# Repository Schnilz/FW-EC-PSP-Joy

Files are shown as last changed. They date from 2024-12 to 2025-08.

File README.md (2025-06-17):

# PSP Joystick Framework Laptop Expansion Card

A joystick expansion card with 2 buttons and the low profile psp joystick.

<p float="left" style="display: flex; flex-wrap: wrap; align-items: center;">
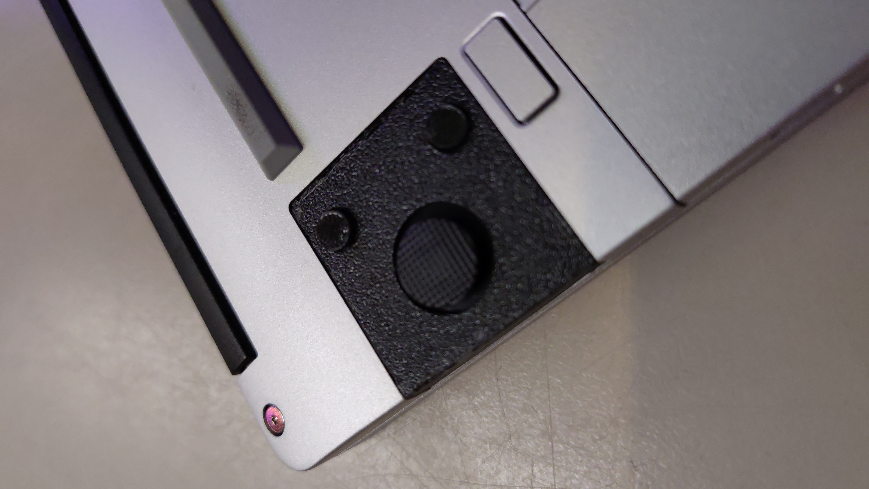
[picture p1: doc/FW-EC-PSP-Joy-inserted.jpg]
  &nbsp;
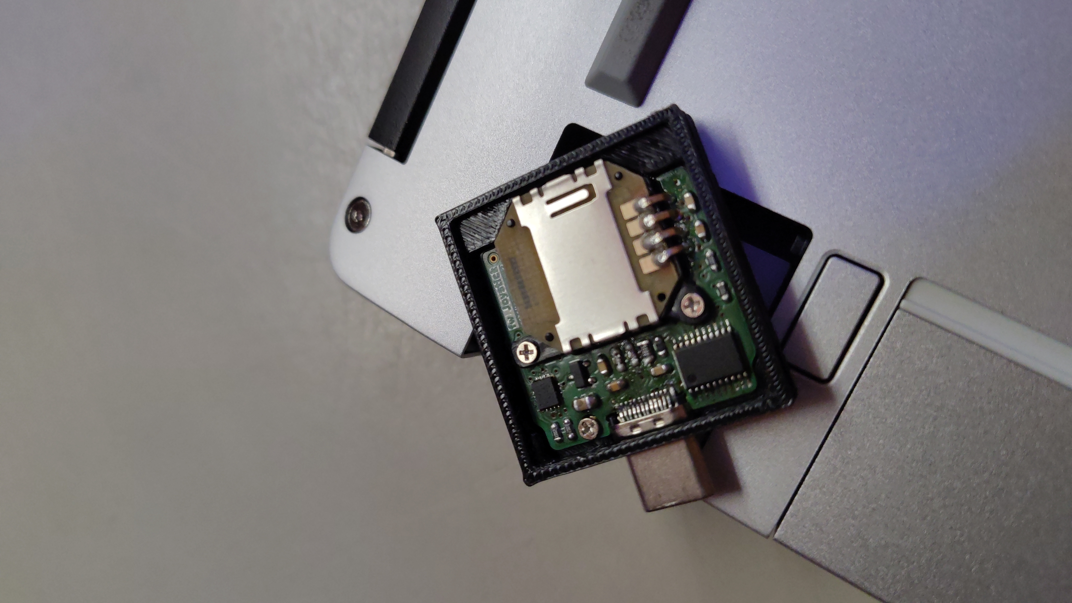
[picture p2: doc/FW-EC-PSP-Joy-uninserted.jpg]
  
</p>

This uses the 10cent risc-v ch32v003 with ch32fun and its software-USB stack rv003usb to power this HID device. 

## PCB

<p float="left" style="display: flex; flex-wrap: wrap; align-items: center;">
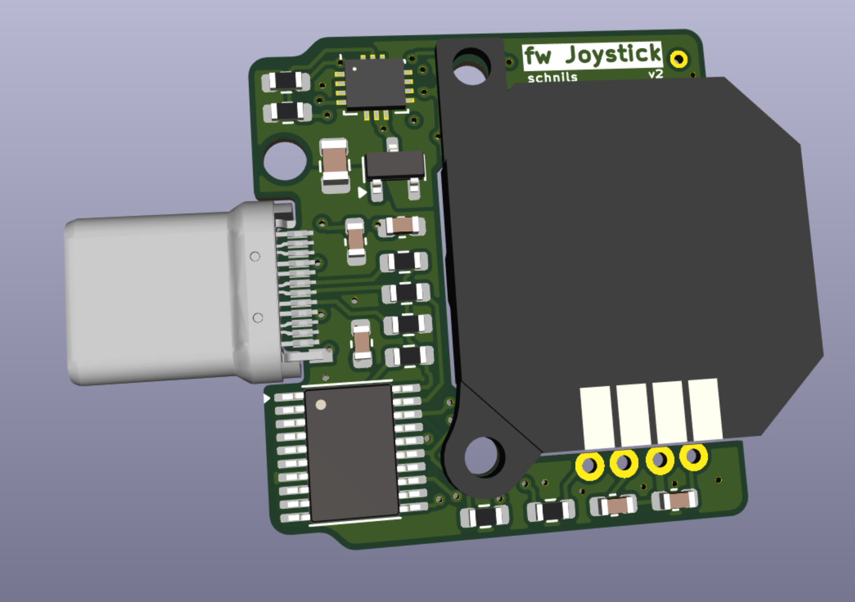
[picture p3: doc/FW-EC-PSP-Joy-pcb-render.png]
  &nbsp;
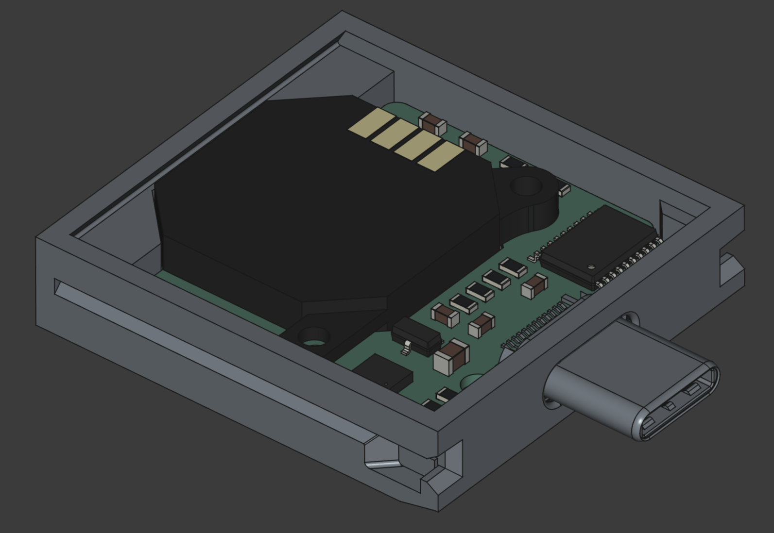
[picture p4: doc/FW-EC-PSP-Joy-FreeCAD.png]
  
</p>

## Thanks

Thanks to LeoDJ for open sourceing his FW-EC-DongleHiderPlus which this is based upon.

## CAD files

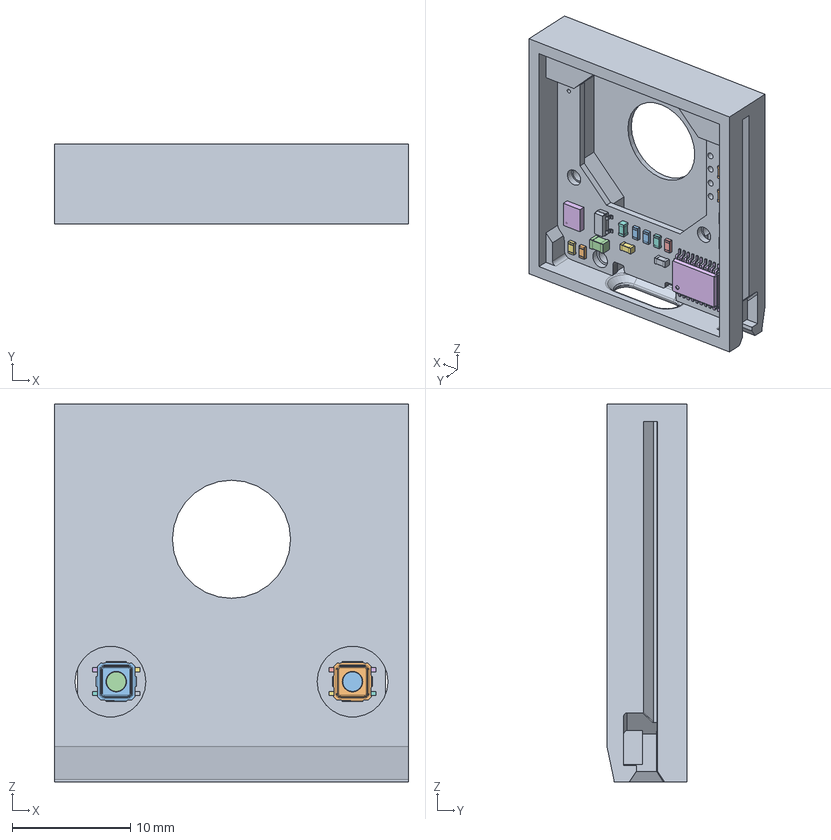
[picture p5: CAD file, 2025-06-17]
mechanical/fw-ce-case.FCStd
30.0 x 6.80 x 32.0 mm
R_0603_1608Metric016
R_0603_1608Metric018
C_0805_2012Metric002
R_0603_1608Metric020
TSSOP_20_44x65mm_P065mm001
R_0603_1608Metric022
R_0603_1608Metric024
C_0603_1608Metric010
C_0603_1608Metric012
R_0603_1608Metric026
R_0603_1608Metric028
R_0603_1608Metric030
Bosch_LGA_14_3x25mm_P05mm001
C_0603_1608Metric014
C_0603_1608Metric016
SOT_024
C_0603_1608Metric018
TS21-34-035-BK-260-SMT-TR v022
TS21-34-035-BK-260-SMT-TR v023
TS21-34-035-BK-260-SMT-TR v024
TS21-34-035-BK-260-SMT-TR v025
TS21-34-035-BK-260-SMT-TR v026
TS21-34-035-BK-260-SMT-TR v027
TS21-34-035-BK-260-SMT-TR v028
TS21-34-035-BK-260-SMT-TR v030
TS21-34-035-BK-260-SMT-TR v031
TS21-34-035-BK-260-SMT-TR v032
TS21-34-035-BK-260-SMT-TR v033
TS21-34-035-BK-260-SMT-TR v034
TS21-34-035-BK-260-SMT-TR v035
TS21-34-035-BK-260-SMT-TR v036
FWPSPJoystick_PCB001

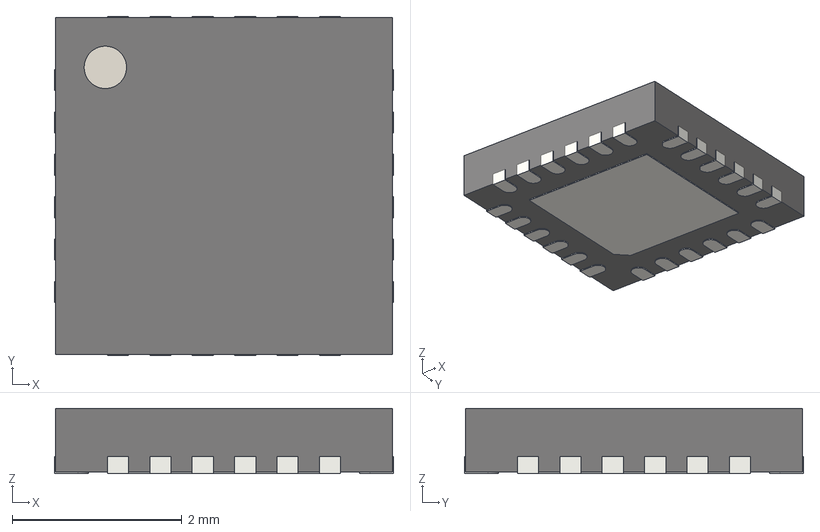
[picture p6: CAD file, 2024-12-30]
pcb/3dshapes/QFN-24-1EP_4x4mm_P0.5mm_EP2.6x2.6mm.step
4.00 x 4.00 x 0.77 mm

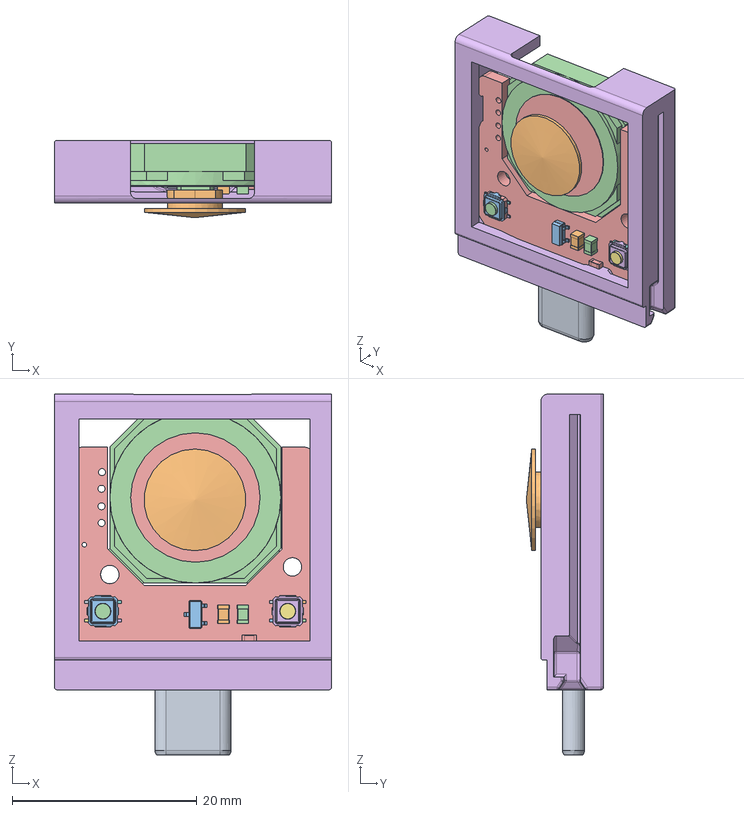
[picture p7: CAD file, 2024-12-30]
Mechanical/testfit.FCStd
30.0 x 8.37 x 39.1 mm
R_0603_1608Metric
C_0603_1608Metric
TSSOP_20_44x65mm_P065mm
PspJoystick v6
PspJoystick v007
PspJoystick v008
PspJoystick v009
PspJoystick v010
PspJoystick v011
PspJoystick v012
R_0603_1608Metric002
R_0603_1608Metric004
C_0603_1608Metric002
R_0603_1608Metric006
Bosch_LGA_14_3x25mm_P05mm
C_0603_1608Metric004
SOT_23_6
TS21-34-035-BK-260-SMT-TR v6
TS21-34-035-BK-260-SMT-TR v007
TS21-34-035-BK-260-SMT-TR v008
TS21-34-035-BK-260-SMT-TR v009
TS21-34-035-BK-260-SMT-TR v010
TS21-34-035-BK-260-SMT-TR v011
TS21-34-035-BK-260-SMT-TR v012
C_0805_2012Metric
SOT_23
C_0805_2012Metric002
C_0603_1608Metric006
TS21-34-035-BK-260-SMT-TR v014
TS21-34-035-BK-260-SMT-TR v015
TS21-34-035-BK-260-SMT-TR v016
TS21-34-035-BK-260-SMT-TR v017
TS21-34-035-BK-260-SMT-TR v018
TS21-34-035-BK-260-SMT-TR v019
TS21-34-035-BK-260-SMT-TR v020
FWPSPJoystick_PCB

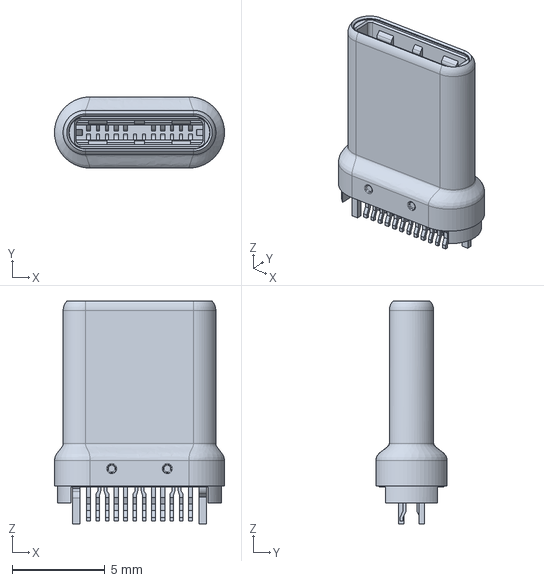
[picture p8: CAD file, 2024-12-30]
pcb/3dshapes/Molex_1054440011.stp
9.18 x 3.84 x 12.0 mm

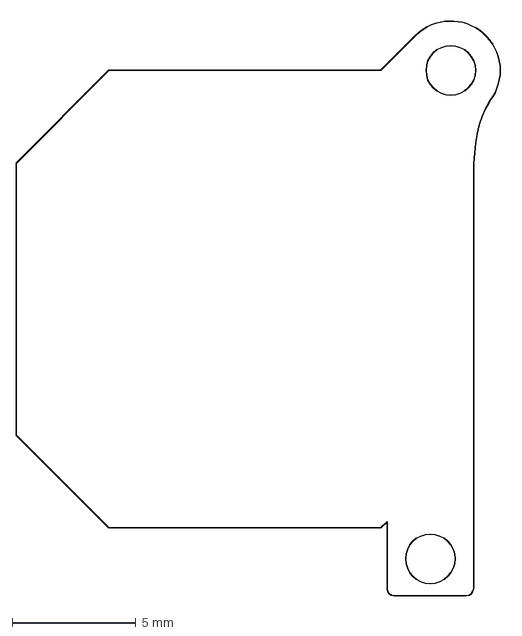
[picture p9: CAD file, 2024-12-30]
Mechanical/psp_joy_outline.dxf
19.8 x 23.4 mm

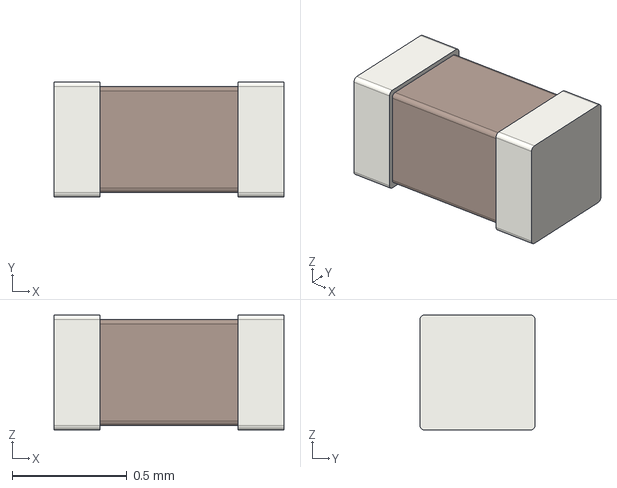
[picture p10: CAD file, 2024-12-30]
pcb/3dshapes/C_0402_1005Metric.step
1.00 x 0.5 x 0.5 mm

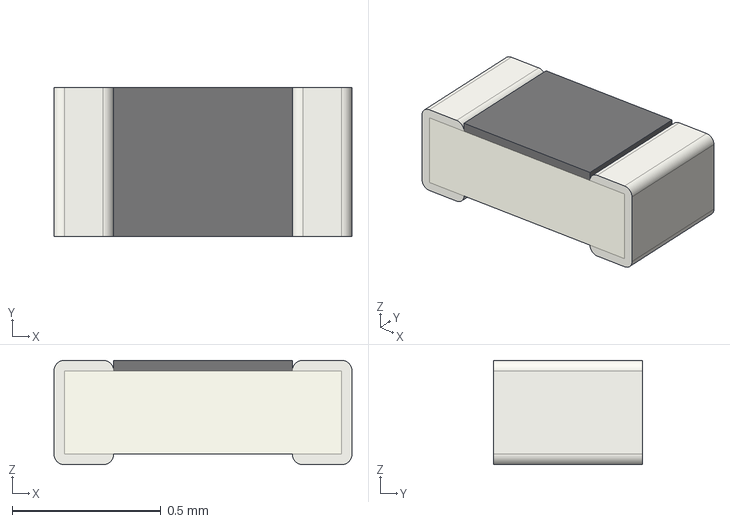
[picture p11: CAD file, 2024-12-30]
pcb/3dshapes/R_0402_1005Metric.step
1.00 x 0.5 x 0.35 mm

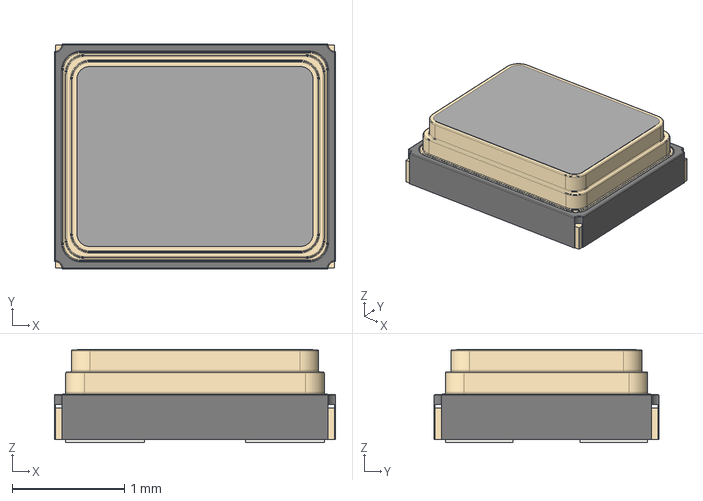
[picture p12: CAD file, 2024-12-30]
pcb/3dshapes/Crystal_SMD_2520-4Pin_2.5x2.0mm.step
2.50 x 2.00 x 0.83 mm

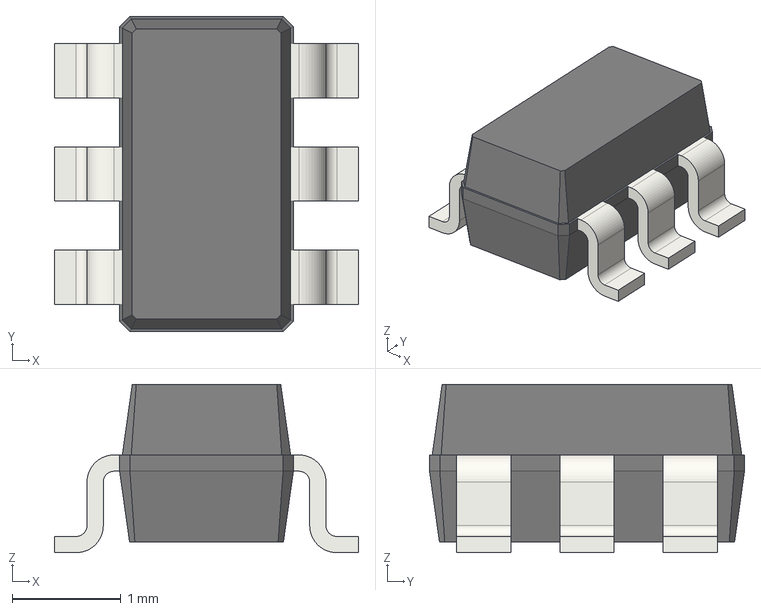
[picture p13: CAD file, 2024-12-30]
pcb/3dshapes/SOT-23-6.step
2.80 x 2.90 x 1.55 mm

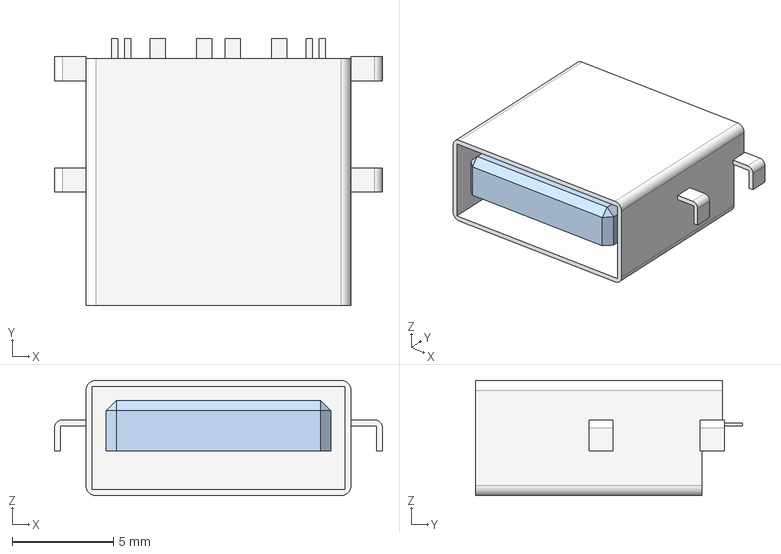
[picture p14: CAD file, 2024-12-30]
pcb/3dshapes/_HC-USB3.0-C345-P.step
16.2 x 13.2 x 5.70 mm

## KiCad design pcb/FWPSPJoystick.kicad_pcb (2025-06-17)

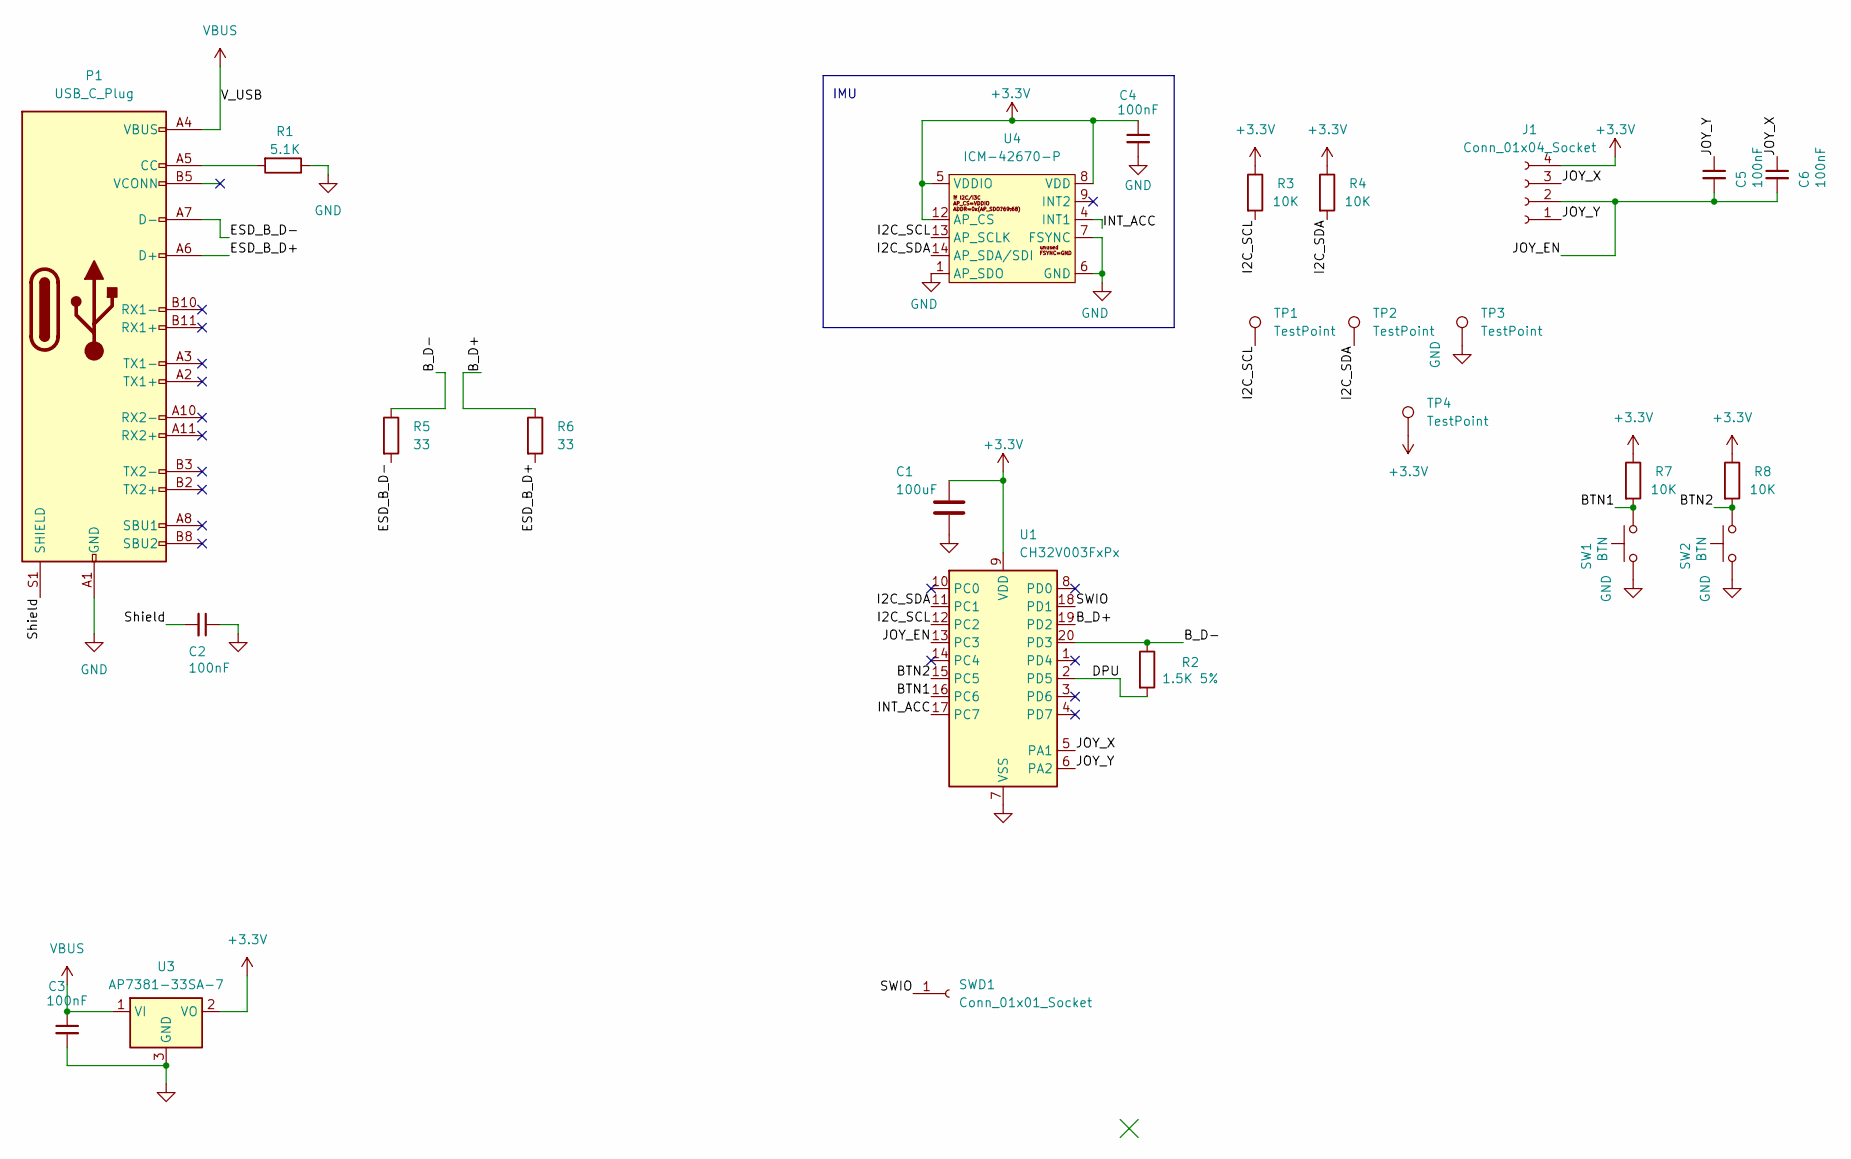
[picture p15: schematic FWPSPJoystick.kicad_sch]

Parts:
C1: 100uF; C_0805_2012Metric; LCSC C440198
C2, C5, C6: 100nF; C_0603_1608Metric; LCSC C14663
C3, C4: 100nF; C_0603_1608Metric
J1: Conn_01x04_Socket; pspjoystick_tht
P1: USB_C_Plug; USB_C_Plug_Molex_105444; LCSC C561769
R1: 5.1K; R_0603_1608Metric; LCSC C23186
R2: 1.5K 5%; R_0603_1608Metric; LCSC C23186
R3, R4, R7, R8: 10K; R_0603_1608Metric
R5, R6: 33; R_0603_1608Metric
SW1, SW2: BTN; TS21
SWD1: Conn_01x01_Socket; TestPoint_THTPad_D1.0mm_Drill0.5mm
TP1, TP2, TP3, TP4: TestPoint; TestPoint_Pad_D1.0mm
U1: CH32V003FxPx; TSSOP-20_4.4x6.5mm_P0.65mm
U3: AP7381-33SA-7; SOT-23
U4: ICM-42670-P; LGA-14_2.5x3x0.76mm

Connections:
+3.3V: C1.1, C4.1, J1.4, R3.1, R4.1, R7.1, R8.1, TP4.1, U1.9 (VDD), U3.2 (VO), U4.5 (VDDIO), U4.8 (VDD), U4.12 (AP_CS)
/BTN1: R7.2, SW1.2, U1.16 (PC6)
/BTN2: R8.2, SW2.2, U1.15 (PC5)
/B_D+: R6.1, U1.19 (PD2)
/B_D-: R2.1, R5.1, U1.20 (PD3)
/DPU: R2.2, U1.2 (PD5)
/ESD_B_D+: P1.A6 (D+), R6.2
/ESD_B_D-: P1.A7 (D-), R5.2
/I2C_SCL: R3.2, TP1.1, U1.12 (PC2), U4.13 (AP_SCLK)
/I2C_SDA: R4.2, TP2.1, U1.11 (PC1), U4.14 (AP_SDA/SDI)
/INT_ACC: U1.17 (PC7), U4.4 (INT1)
/JOY_EN: C5.2, C6.2, J1.2, U1.13 (PC3)
/JOY_X: C6.1, J1.3, U1.5 (PA1)
/JOY_Y: C5.1, J1.1, U1.6 (PA2)
/SWIO: SWD1.1, U1.18 (PD1)
/Shield: C2.2, P1.S1 (SHIELD)
GND: C1.2, C2.1, C3.2, C4.2, P1.A1 (GND), P1.A12 (GND), P1.B1 (GND), P1.B12 (GND), R1.1, SW1.1, SW2.1, TP3.1, U1.7 (VSS), U3.3 (GND), U4.1 (AP_SDO), U4.6 (GND), U4.7 (FSYNC)
unnamed: P1.A5 (CC), R1.2
VBUS: C3.1, P1.A4 (VBUS), P1.A9 (VBUS), P1.B4 (VBUS), P1.B9 (VBUS), U3.1 (VI)

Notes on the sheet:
IMU

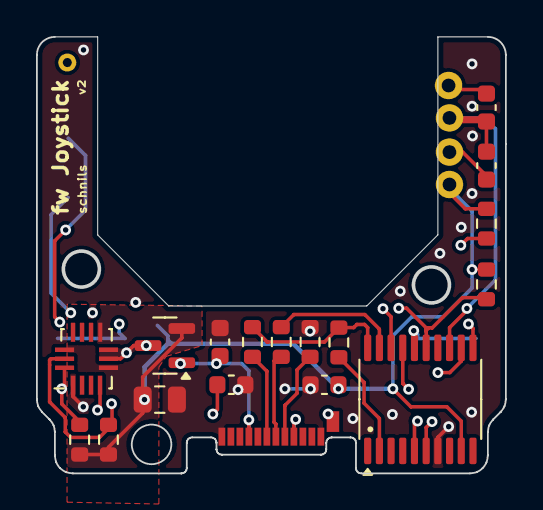
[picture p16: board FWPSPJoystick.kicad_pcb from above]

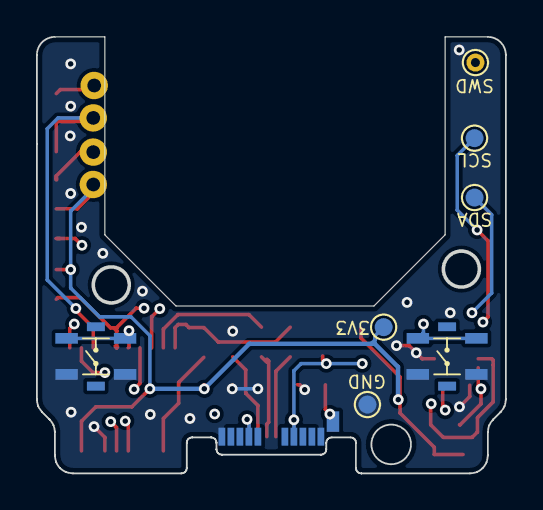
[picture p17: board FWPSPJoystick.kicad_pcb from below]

Board: 4 copper layers, 26.1 x 24.2 mm, 26 parts (7 on the bottom side), 19 nets.

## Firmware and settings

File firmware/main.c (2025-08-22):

#include "ch32v003fun.h"
#include "gamepad_config.h"
#include "rv003usb.h"
#include <stdio.h>
#include <string.h>

void init(void);

/* Board drivers */
#include "ch32v003_flash.h"
#include "lib_i2c.h"
#include "system_interface.h"

/* Static functions definition */
static int setup_imu();
static void init(void);

/* Static variables */
static inv_imu_device_t imu_dev; /* Driver structure */
volatile unsigned long uptime_10ms = 0;
volatile unsigned long last_usb_packet_10ms = 0;
volatile unsigned long calibration_button_timout = 0;

volatile bool calibration_mode = false;

#define ADC_NUMCHLS 2
const int adc_half_value = (1 << 10) / 2;
volatile uint16_t adc_buffer[ADC_NUMCHLS];
uint16_t adc_buffer_min[ADC_NUMCHLS] = {0xFFFF - 1, 0xFFFF - 1};
uint16_t adc_buffer_max[ADC_NUMCHLS] = {1, 1};
uint16_t adc_buffer_deadzone_min[ADC_NUMCHLS] = {0xFFFF - 1, 0xFFFF - 1};
uint16_t adc_buffer_deadzone_max[ADC_NUMCHLS] = {1, 1};
uint16_t zero_offset[ADC_NUMCHLS] = {0, 0};

#define STANDBY_AFTER_DURATION_10MS 10
#define CALIBRATION_MODE_BUTTON_10MS 800

#define NONVOLATILE_START_ADDR FLASH_PRECALCULATE_NONVOLATILE_ADDR(0)
#define NONVLOATILE_VAR_ADDR FLASH_PRECALCULATE_NONVOLATILE_ADDR(10)

#define MIN(a, b) (a < b ? a : b)
#define MAX(a, b) (a > b ? a : b)

static volatile uint8_t tsajoystick[3] = {0x00, 0x00, 0x00};

// #define STATUS_LED
// #define STATUS_LED_PIN PC3

void enter_sleep() {
  // enable power interface module clock
  RCC->APB1PCENR |= RCC_APB1Periph_PWR;

  // enable low speed oscillator (LSI)
  RCC->RSTSCKR |= RCC_LSION;
  while ((RCC->RSTSCKR & RCC_LSIRDY) == 0) {
  };

  // enable AutoWakeUp event
  EXTI->EVENR |= EXTI_Line9;
  EXTI->FTENR |= EXTI_Line9;

  // configure AWU prescaler
  PWR->AWUPSC |= PWR_AWU_Prescaler_61440;

  // configure AWU window comparison value
  PWR->AWUWR &= ~0x3f;
  PWR->AWUWR |= 63; // 1 - 63

  // enable AWU
  PWR->AWUCSR |= (1 << 1);

  // select standby on power-down
  PWR->CTLR |= PWR_CTLR_PDDS;

  // peripheral interrupt controller send to deep sleep
  PFIC->SCTLR |= (1 << 2);

  __WFE();
  init();
}

// I2C Scan Callback example function. Prints the address which responded
static bool i2c_init_ok = false;
static int found_i2c_dev = 0;
static uint8_t i2c_addr = 0;
void i2c_scan_callback(const uint8_t addr) {
  found_i2c_dev += 1;
  i2c_addr = addr;
  // printf("Address: 0x%02X Responded.\n", addr);
}

bool imu_self_test();

static inline uint8_t fast_lerp_u16_to_u8(uint16_t value, uint16_t min_value,
                                          uint16_t max_value,
                                          uint8_t min_target,
                                          uint8_t max_target) {
  if (value <= min_value)
    return min_target;
  if (value >= max_value)
    return max_target;

  uint32_t in_range = (uint32_t)(max_value - min_value);
  uint32_t out_range = (uint32_t)(max_target - min_target);

  uint32_t scaled = (uint32_t)(value - min_value) * out_range;

  // add half of denominator for rounding (instead of truncation)
  uint32_t mapped = (scaled + in_range / 2) / in_range;

  return (uint8_t)(min_target + mapped);
}

void calc_values() {

  bool both_in_deadzone = true;
  for (int ax = 0; ax < 2; ax += 1) {
    const int16_t deadzone_width =
        (adc_buffer_deadzone_max[ax] - adc_buffer_deadzone_min[ax]);
    const int16_t deadzone_tolerance =
        deadzone_width * 0.15; /* 15% deadzone tolerance*/
    const bool out_of_deadzone =
        (adc_buffer[ax] < adc_buffer_deadzone_min[ax] - deadzone_tolerance ||
         adc_buffer[ax] > adc_buffer_deadzone_max[ax] + deadzone_tolerance);
    if (out_of_deadzone) {
      both_in_deadzone = false;
    }
  }

  for (int ax = 0; ax < 2; ax += 1) {
    const unsigned int mapped_axis = ax ? 0 : 1;
    const uint8_t gamepad_mid = (GAMEPAD_LOGICAL_MAX + GAMEPAD_LOGICAL_MIN) / 2;
    if (adc_buffer[ax] > 10 && adc_buffer[ax] < ((1 << 10) - 11) &&
        !both_in_deadzone) {
      const bool lower = (adc_buffer[ax] < zero_offset[ax]);
      const uint16_t min = lower ? adc_buffer_min[ax] : zero_offset[ax];
      const uint16_t max = lower ? zero_offset[ax] : adc_buffer_max[ax];
      tsajoystick[mapped_axis] = fast_lerp_u16_to_u8(
          adc_buffer[ax], min, max, lower ? GAMEPAD_LOGICAL_MIN : gamepad_mid,
          lower ? gamepad_mid : GAMEPAD_LOGICAL_MAX);
    } else {
      tsajoystick[mapped_axis] = gamepad_mid;
    }
  }
  tsajoystick[2] = ((GPIOC->INDR & (1 << 5)) ? 0 : 1 << 0) |
                   ((GPIOC->INDR & (1 << 6)) ? 0 : 1 << 1);
}

int main() {
  init();
  while (1) {
    calc_values();
    Delay_Ms(5);
    calc_values();
    Delay_Ms(5);
#if defined(STATUS_LED)
    funDigitalWrite(STATUS_LED_PIN, 1);
#endif
    uptime_10ms++;

    const bool button1_pressed = !(GPIOC->INDR & (1 << 5));
    const bool button2_pressed = !(GPIOC->INDR & (1 << 6));

    if (calibration_mode) {
      if (button1_pressed) {
        for (int ax = 0; ax < 2; ax += 1) {
          if (adc_buffer[ax] > 10 && adc_buffer[ax] < ((1 << 10) - 11)) {
            adc_buffer_deadzone_min[ax] =
                MIN(adc_buffer_deadzone_min[ax], adc_buffer[ax]);
            adc_buffer_deadzone_max[ax] =
                MAX(adc_buffer_deadzone_max[ax], adc_buffer[ax]);
          }
        }
        for (int ax = 0; ax < 2; ax += 1) {
          zero_offset[ax] =
              ((adc_buffer_deadzone_min[ax] + adc_buffer_deadzone_max[ax]) / 2);
        }
      } else {
        for (int ax = 0; ax < 2; ax += 1) {
          if (adc_buffer[ax] > 10 && adc_buffer[ax] < ((1 << 10) - 11)) {
            adc_buffer_min[ax] = MIN(adc_buffer_min[ax], adc_buffer[ax]);
            adc_buffer_max[ax] = MAX(adc_buffer_max[ax], adc_buffer[ax]);
          }
        }
      }
    }

    if (button1_pressed && button2_pressed) {
      if (calibration_button_timout++ > CALIBRATION_MODE_BUTTON_10MS) {
        if (calibration_mode) {
          flash_unlock();
          flash_erase_page(
              NONVOLATILE_START_ADDR); // Erase a 64-bit block of flash memory
          flash_erase_page(NONVOLATILE_START_ADDR + 64);
          for (int ax = 0; ax < 2; ax += 1) {
            flash_program_16(NONVOLATILE_START_ADDR + ax * 8 + 0,
                             adc_buffer_deadzone_max[ax]);
            flash_program_16(NONVOLATILE_START_ADDR + ax * 8 + 2,
                             adc_buffer_deadzone_min[ax]);
            flash_program_16(NONVOLATILE_START_ADDR + ax * 8 + 4,
                             adc_buffer_max[ax]);
            flash_program_16(NONVOLATILE_START_ADDR + ax * 8 + 6,
                             adc_buffer_min[ax]);
          }
          flash_lock();

          /* to bootloader */
          FLASH->BOOT_MODEKEYR = 0x45670123;
          FLASH->BOOT_MODEKEYR = 0xCDEF89AB;
          FLASH->STATR = 0x4000;
          RCC->RSTSCKR |= 0x1000000;
          PFIC->CFGR = 0xBEEF0080;
        }
        calibration_mode = true;
        calibration_button_timout = 0;
        for (int ax = 0; ax < 2; ax += 1) {
          adc_buffer_min[ax] = 0xFFFF - 1;
          adc_buffer_max[ax] = 1;
          adc_buffer_deadzone_min[ax] = 0xFFFF - 1;
          adc_buffer_deadzone_max[ax] = 1;
        }
      }
    } else {
      calibration_button_timout = 0;
    }
    if (last_usb_packet_10ms + STANDBY_AFTER_DURATION_10MS < uptime_10ms) {
      enter_sleep();
      uptime_10ms = 0;
      last_usb_packet_10ms = STANDBY_AFTER_DURATION_10MS;
#if defined(PC3_STATUS_LED)
      funDigitalWrite(PC3, 0);
#endif
    }
  };
}

/*
 * initialize adc for DMA
 */
void init(void) {
  SystemInit();
  Delay_Ms(1); // Ensures USB re-enumeration after bootloader or reset; Spec
               // demand >2.5µs ( TDDIS )
  // ADCCLK = 24 MHz => RCC_ADCPRE = 0: divide by 2
  RCC->CFGR0 &= ~(0x1F << 11);

  // Enable GPIOA, GPIOC and ADC
  RCC->APB2PCENR |= RCC_APB2Periph_GPIOA | RCC_APB2Periph_GPIOC |
                    RCC_APB2Periph_AFIO | RCC_APB2Periph_ADC1;

  flash_set_latency();
  for (int ax = 0; ax < 2; ax += 1) {
    adc_buffer_deadzone_max[ax] =
        flash_read_16_bits(NONVOLATILE_START_ADDR + ax * 8 + 0);
    adc_buffer_deadzone_min[ax] =
        flash_read_16_bits(NONVOLATILE_START_ADDR + ax * 8 + 2);
    adc_buffer_max[ax] =
        flash_read_16_bits(NONVOLATILE_START_ADDR + ax * 8 + 4);
    adc_buffer_min[ax] =
        flash_read_16_bits(NONVOLATILE_START_ADDR + ax * 8 + 6);

    zero_offset[ax] =
        ((adc_buffer_deadzone_min[ax] + adc_buffer_deadzone_max[ax]) / 2);
  }

  // flash_erase_page(NONVOLATILE_START_ADDR);
  // zero_offset = flash_read_16_bits(NONVLOATILE_VAR_ADDR);
#if defined(STATUS_LED)
  funPinMode(STATUS_LED_PIN, GPIO_CFGLR_OUT_2Mhz_OD);
  funDigitalWrite(STATUS_LED_PIN, 1);
#endif
  funPinMode(PC3, GPIO_CFGLR_OUT_2Mhz_OD);
  funDigitalWrite(PC3, 1);
#endif
  funPinMode(PC5, GPIO_CFGLR_IN_PUPD);
  funPinMode(PC7, GPIO_CFGLR_IN_PUPD);
  funDigitalWrite(PC5, 1);
  funDigitalWrite(PC7, 1);

  // PA1 is analog input chl 1
  funPinMode(PA1, GPIO_CFGLR_IN_ANALOG);
  // PA2 is analog input chl 0
  funPinMode(PA2, GPIO_CFGLR_IN_ANALOG);

  // Reset the ADC to init all regs
  RCC->APB2PRSTR |= RCC_APB2Periph_ADC1;
  RCC->APB2PRSTR &= ~RCC_APB2Periph_ADC1;

  // Set up four conversions on chl 1, 0
  ADC1->RSQR1 = (ADC_NUMCHLS - 1) << 20; // four chls in the sequence
  ADC1->RSQR2 = 0;
  ADC1->RSQR3 = 0;
  ADC1->RSQR3 = (1 << (5 * 0)) | (0 << (5 * 1));

  // set sampling time for chl 0, 1
  // 0:7 => 3/9/15/30/43/57/73/241 cycles
  ADC1->SAMPTR2 = (6 << (3 * 0)) | (6 << (3 * 1));

  // turn on ADC
  ADC1->CTLR2 |= ADC_ADON;

  // Reset calibration
  ADC1->CTLR2 |= ADC_RSTCAL;
  while (ADC1->CTLR2 & ADC_RSTCAL)
    ;

  // Calibrate
  ADC1->CTLR2 |= ADC_CAL;
  while (ADC1->CTLR2 & ADC_CAL)
    ;

  // Turn on DMA
  RCC->AHBPCENR |= RCC_AHBPeriph_DMA1;

  // DMA1_Channel1 is for ADC
  DMA1_Channel1->PADDR = (uint32_t)&ADC1->RDATAR;
  DMA1_Channel1->MADDR = (uint32_t)adc_buffer;
  DMA1_Channel1->CNTR = ADC_NUMCHLS;
  DMA1_Channel1->CFGR = DMA_M2M_Disable | DMA_Priority_VeryHigh |
                        DMA_MemoryDataSize_HalfWord |
                        DMA_PeripheralDataSize_HalfWord | DMA_MemoryInc_Enable |
                        DMA_Mode_Circular | DMA_DIR_PeripheralSRC;

  // Turn on DMA channel 1
  DMA1_Channel1->CFGR |= DMA_CFGR1_EN;

  // enable scanning
  ADC1->CTLR1 |= ADC_SCAN;

  // Enable continuous conversion and DMA
  ADC1->CTLR2 |= ADC_CONT | ADC_DMA | ADC_EXTSEL;

  // start conversion
  ADC1->CTLR2 |= ADC_SWSTART;

  usb_setup();
  // i2c_init_ok = !i2c_init(I2C_CLK_400KHZ);
  // Delay_Ms(100);
  //  i2c_scan(i2c_scan_callback);
  //  i2c_addr = i2c_addr == 0x68 ? 1 : 0;
  // while(1) {
  // i2c_addr |= setup_imu() == 0 ? 1 << 1 : 0;
  // Delay_Ms(1000);
  //}  // imu_self_test();
}

// static int setup_imu() {
//   int rc = 0;
//   inv_imu_serif_t imu_serif;
//   uint8_t whoami;

//   /* Initialize serial interface between MCU and IMU */
//   imu_serif.context = 0; /* no need */
//   imu_serif.read_reg = si_io_imu_read_reg;
//   imu_serif.write_reg = si_io_imu_write_reg;
//   imu_serif.max_read =
//       8; /* maximum number of bytes allowed per serial read */
//   imu_serif.max_write =
//       8; /* maximum number of bytes allowed per serial write */
//   imu_serif.serif_type = UI_I2C;

//   /* Init device */
//   rc |= inv_imu_init(&imu_dev, &imu_serif, NULL);
//   SI_CHECK_RC(rc);

//   return rc;
// #if SERIF_TYPE == UI_SPI4
//   /* Configure slew-rate to 19 ns (required when using EVB) */
//   rc |= inv_imu_set_spi_slew_rate(&imu_dev,
//                                   DRIVE_CONFIG3_SPI_SLEW_RATE_MAX_19_NS);
//   SI_CHECK_RC(rc);
// #endif

//   /* Check WHOAMI */
//   rc |= inv_imu_get_who_am_i(&imu_dev, &whoami);
//   SI_CHECK_RC(rc);
//   if (whoami != INV_IMU_WHOAMI) {
//     INV_MSG(INV_MSG_LEVEL_ERROR, "Erroneous WHOAMI value.");
//     INV_MSG(INV_MSG_LEVEL_ERROR, "  - Read 0x%02x", whoami);
//     INV_MSG(INV_MSG_LEVEL_ERROR, "  - Expected 0x%02x", INV_IMU_WHOAMI);
//     return INV_ERROR;
//   }

//   return rc;
// }

// bool imu_self_test() {
//
//   int rc = 0;
//   int retries = 0;
//   do {
//     int rc = 0;
//     static int iter = 0;
//     inv_imu_selftest_output_t out;
//     inv_imu_selftest_parameters_t params;
//
//     rc |= inv_imu_init_selftest_parameters_struct(&imu_dev, &params);
//     /* Update `params` if needed here */
//     rc |= inv_imu_run_selftest(&imu_dev, params, &out);
//     SI_CHECK_RC(rc);
//
//     /* Print self-test status */
//     INV_MSG(INV_MSG_LEVEL_INFO, "[%u] Accel self-test %s", iter,
//             out.accel_status == 1 ? "OK" : "KO");
//     if (out.accel_status != 1) {
//       INV_MSG(INV_MSG_LEVEL_VERBOSE, "  - Accel X: %s",
//               out.ax_status == 1 ? "OK" : "KO");
//       INV_MSG(INV_MSG_LEVEL_VERBOSE, "  - Accel Y: %s",
//               out.ay_status == 1 ? "OK" : "KO");
//       INV_MSG(INV_MSG_LEVEL_VERBOSE, "  - Accel Z: %s",
//               out.az_status == 1 ? "OK" : "KO");
//       rc |= INV_ERROR;
//       i2c_addr |=1 << 2;
//     }
//
// #if INV_IMU_IS_GYRO_SUPPORTED
//     INV_MSG(INV_MSG_LEVEL_INFO, "[%u] Gyro self-test %s", iter,
//             out.gyro_status == 1 ? "OK" : "KO");
//     if (out.gyro_status != 1) {
//       INV_MSG(INV_MSG_LEVEL_VERBOSE, "  - Gyro X: %s",
//               out.gx_status == 1 ? "OK" : "KO");
//       INV_MSG(INV_MSG_LEVEL_VERBOSE, "  - Gyro Y: %s",
//               out.gy_status == 1 ? "OK" : "KO");
//       INV_MSG(INV_MSG_LEVEL_VERBOSE, "  - Gyro Z: %s",
//               out.gz_status == 1 ? "OK" : "KO");
//       rc |= INV_ERROR;
//       i2c_addr |=1 << 3;
//     }
//
//     /* Check incomplete state */
//     if (out.gyro_status & 0x2) {
//       INV_MSG(INV_MSG_LEVEL_ERROR, "[%u] Gyro self-test are incomplete.",
//       iter); rc |= INV_ERROR; i2c_addr |=1 << 4;
//     }
// #endif
//
//     iter++;
//
//     /* Print empty line to ease readability */
//     INV_MSG(INV_MSG_LEVEL_INFO, "");
//   } while (rc == 0 && retries++ < 4);
//   return rc;
// }

void usb_handle_user_in_request(struct usb_endpoint *e, uint8_t *scratchpad,
                                int endp, uint32_t sendtok,
                                struct rv003usb_internal *ist) {
  if (endp) {

#if defined(PC3_STATUS_LED)
    funDigitalWrite(PC3, 0);
#endif
    if (calibration_mode) {
      tsajoystick[2] = 0;
    }

    tsajoystick[2] = ((GPIOC->INDR & (1 << 5)) ? 0 : (1 << 0)) |
                     ((GPIOC->INDR & (1 << 6)) ? 0 : (1 << 1));
    usb_send_data((const void *)tsajoystick, sizeof(tsajoystick), 0, sendtok);

#if defined(PC3_STATUS_LED)
    funDigitalWrite(PC3, 1);
#endif
    last_usb_packet_10ms = uptime_10ms;
  } else {
    // If it's a control transfer, nak it.
    usb_send_empty(sendtok);
  }
}

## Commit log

2024-12-30 initial Joystick version
    [BOM-DongleHiderPlus_PCB.csv, C_0402_1005Metric.step, Crystal_SMD_2520-4Pin_2.5x2.0mm.step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]
2025-08-22 save calibration to flash

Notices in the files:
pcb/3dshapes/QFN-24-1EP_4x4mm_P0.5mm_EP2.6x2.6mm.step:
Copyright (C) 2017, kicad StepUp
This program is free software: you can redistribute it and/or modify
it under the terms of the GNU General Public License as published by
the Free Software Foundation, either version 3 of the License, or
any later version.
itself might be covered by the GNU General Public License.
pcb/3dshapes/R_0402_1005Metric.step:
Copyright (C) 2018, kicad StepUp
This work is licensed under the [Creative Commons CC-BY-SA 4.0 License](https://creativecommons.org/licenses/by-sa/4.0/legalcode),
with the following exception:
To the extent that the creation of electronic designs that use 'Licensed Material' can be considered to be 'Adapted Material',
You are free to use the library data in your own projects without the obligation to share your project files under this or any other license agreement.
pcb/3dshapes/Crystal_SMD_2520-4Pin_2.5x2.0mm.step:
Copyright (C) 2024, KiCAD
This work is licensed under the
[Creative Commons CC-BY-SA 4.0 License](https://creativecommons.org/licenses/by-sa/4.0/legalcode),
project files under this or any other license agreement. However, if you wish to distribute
